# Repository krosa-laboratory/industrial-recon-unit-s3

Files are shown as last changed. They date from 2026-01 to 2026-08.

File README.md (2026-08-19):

# Tactical Cyber-Recon Architecture (Edge-to-C2)

A distributed, Wireless Intrusion Detection System (WIDS) and Signal Intelligence (SIGINT) platform. 

This project separates data acquisition from analysis. It utilizes an ESP32-S3 as a headless, RF edge sensor that streams raw 802.11 and BLE frames via high-speed telemetry to a Python-based Command & Control station for real-time processing, OSINT enrichment, and visualization.

## The Edge Node (Headless ESP32-S3)
A bare-metal, RTOS-driven sensor optimized for maximum radio duty-cycle and zero GUI overhead.

* **MCU:** ESP32-S3-WROOM-1 (Dual-Core Xtensa LX7)
* **Firmware:** PlatformIO / FreeRTOS (C++)
* **Architecture:**
  * **Core 0 (RF Engine):** Dedicated to hardware-level interrupts, 802.11 Promiscuous mode, CSI (Channel State Information) extraction, and passive BLE scanning.
  * **Core 1 (Telemetry Link):** Dedicated to consuming RTOS queues, serializing data into lightweight JSON, and streaming via UART at 921600 baud without blocking the radio.

## The Command & Control Station (Python GUI)
A desktop application for data ingestion, decoding, and tactical analysis.

* **Tech Stack:** Python 3, PyQt6 (UI/UX), PyQtGraph (Real-time data viz), PySerial (Async ingestion).
* **Key Capabilities:**
  * **OSINT Tracker:** Cross-references captured MAC addresses with local OUI databases to identify device manufacturers and track historical Wi-Fi probe requests.
  * **WIDS Dashboard:** Real-time detection of Deauthentication bursts, Rogue APs, and BLE saturation attacks.
  * **CSI Radar:** Generates live waterfall plots from 802.11 subcarrier perturbations to detect physical presence via microwave reflections.
  * **BLE Ecosystem Sniffer:** Parses raw Bluetooth Low Energy payloads to track corporate/IoT devices and exposes unencrypted GATT profiles.

## 🛠️ Development Philosophy & Post-Mortem
*Note: This architecture is a evolution from an initial monolithic design. By pivoting to a headless, distributed model, the system bypasses the processing and memory constraints of local displays (LVGL) and transceivers. This shift dedicates 100% of the ESP32’s compute power and RAM to raw RF acquisition, while offloading heavy OSINT and data visualization workloads to the Command & Control station.*

## ⚠️ Disclaimer
This tool is strictly for educational research, Functional Safety (FuSa) testing, and authorized auditing of Industrial Control Systems (ICS) and corporate networks.

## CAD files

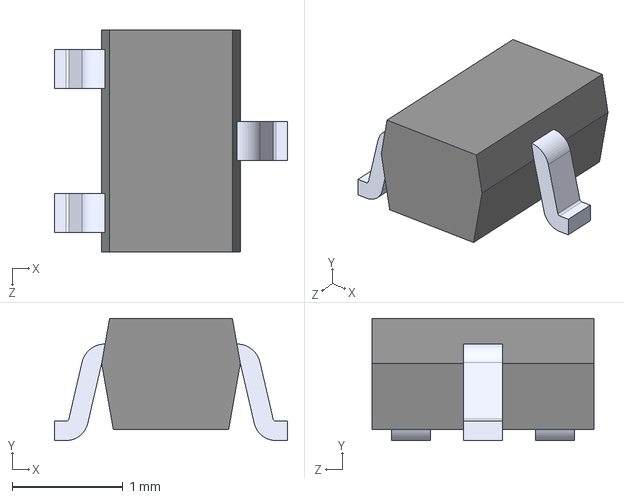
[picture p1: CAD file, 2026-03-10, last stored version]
Hardware/Industrial-Protocol-Auditor-Hardware_V3/Components/PESD2CANFD24V-UX.step
2.10 x 1.10 x 2.00 mm

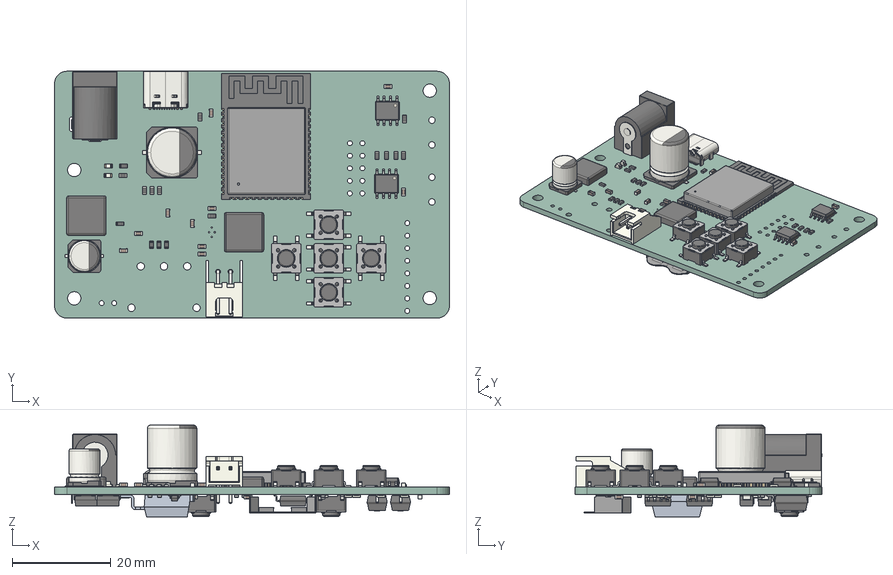
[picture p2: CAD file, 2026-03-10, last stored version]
Hardware/Industrial-Protocol-Auditor-Hardware_V3/Industrial-Protocol-Auditor-Hardware.step
80.0 x 50.1 x 18.6 mm
L_Coilcraft_XAL7020-102 x 2
C_0603_1608Metric x 15
R_0603_1608Metric x 33
SOIC-8_3.9x4.9mm_P1.27mm x 2
ESP32-S3-WROOM-1
SW_SPST_PTS645Sx43SMTR92 x 7
CP_Elec_6.3x7.7
LED_0603_1608Metric x 2
CP_Elec_10x12.5
BarrelJack_Horizontal
USB_C_Receptacle_GCT_USB4105-xx-A_16P_TopMnt_Horizontal
JST_XH_S2B-XH-A_1x02_P2.50mm_Horizontal
SOIC-8_5.3x5.3mm_P1.27mm x 2
SW_DIP_SPSTx01_Slide_6.7x4.1mm_W6.73mm_P2.54mm_LowProfile_JPin x 2
SOT-23
Industrial-Protocol-Auditor-Hardware 1.54.1
D_SMA x 4
BatteryHolder_LINX_BAT-HLD-012-SMT
Fuse_1206_3216Metric
Industrial-Protocol-Auditor-Hardware_PCB

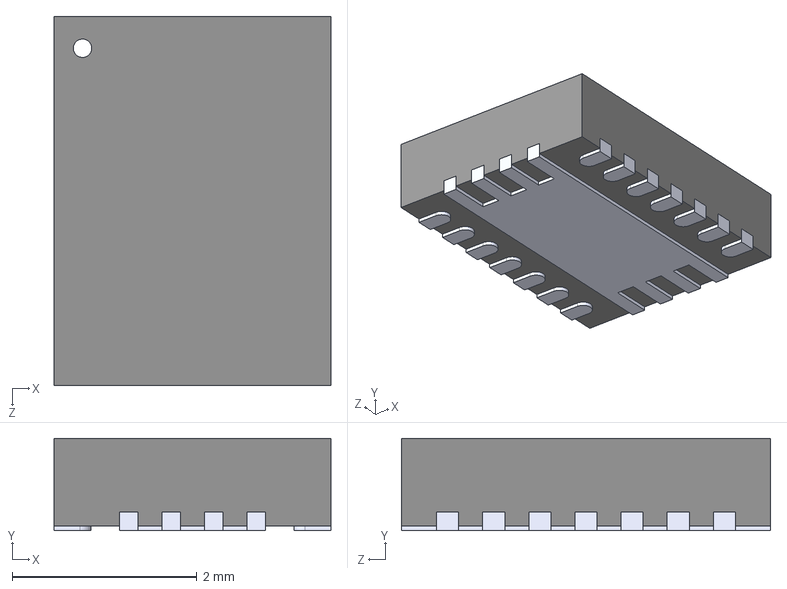
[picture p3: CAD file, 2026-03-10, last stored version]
Hardware/Industrial-Protocol-Auditor-Hardware_V3/Components/TPS63020DSJR.step
3.00 x 1.00 x 4.00 mm

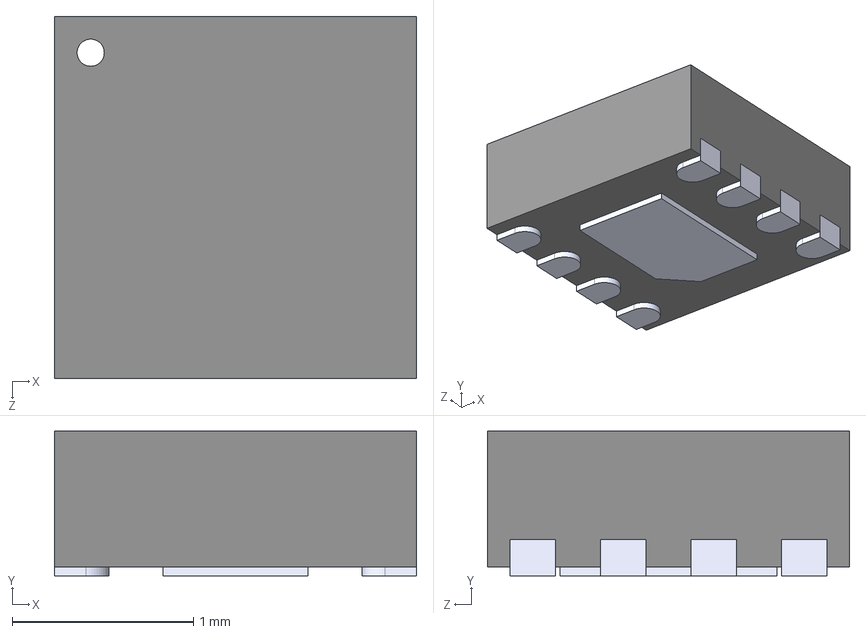
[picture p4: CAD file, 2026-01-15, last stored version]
Hardware/Industrial-Protocol-Auditor-Hardware_V3/Components/MAX17048G_T10.step
2.00 x 0.8 x 2.00 mm

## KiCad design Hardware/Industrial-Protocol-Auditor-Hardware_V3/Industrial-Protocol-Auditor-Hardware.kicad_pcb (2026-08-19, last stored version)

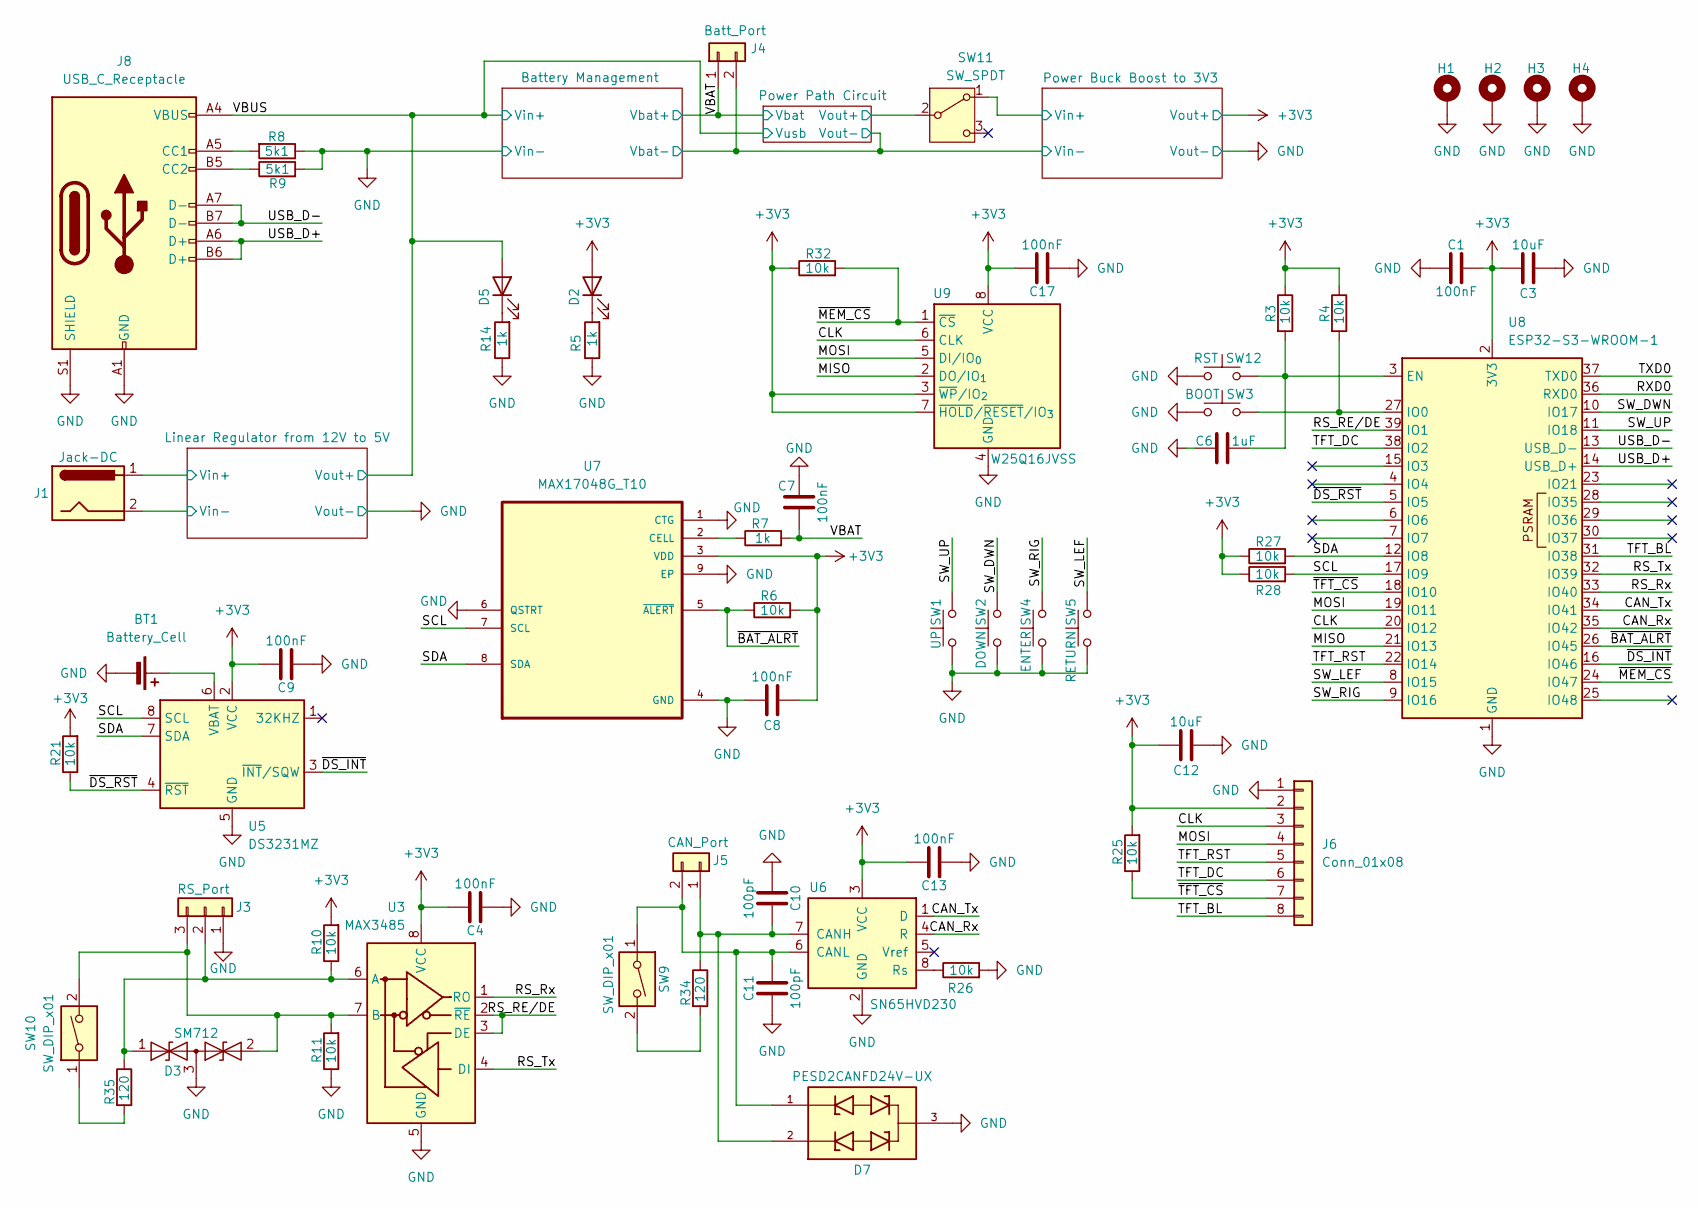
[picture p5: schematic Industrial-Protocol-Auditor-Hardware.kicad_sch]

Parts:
BT1: Battery_Cell; BatteryHolder_LINX_BAT-HLD-012-SMT; LCSC Part C964817
C1, C4, C7, C8, C9, C13, C17: 100nF; C_0603_1608Metric; LCSC Part C14663
C3, C12: 10uF; C_0603_1608Metric; LCSC Part C19702
C6: 1uF; C_0603_1608Metric; LCSC Part C15849
C10, C11: 100pF; C_0603_1608Metric; LCSC Part C14858
D2, D5: LED; LED_0603_1608Metric; LCSC Part C2286
D3: SM712; SOT-23; LCSC Part C7420375
D7: PESD2CANFD24V-UX; SOT-23; PARTREV V.4; LCSC Part C2687131
H1, H2, H3, H4: MountingHole_Pad; MountingHole_2.7mm_M2.5
J1: Jack-DC; BarrelJack_Horizontal; LCSC Part C16214
J3: RS_Port; TerminalBlock_MaiXu_MX126-5.0-03P_1x03_P5.00mm; LCSC Part C474882
J4: Batt_Port; JST_XH_S2B-XH-A_1x02_P2.50mm_Horizontal; LCSC Part C157931
J5: CAN_Port; TerminalBlock_MaiXu_MX126-5.0-02P_1x02_P5.00mm; LCSC Part C474881
J6: Conn_01x08; PinHeader_1x08_P2.54mm_Vertical; LCSC Part C157914
J8: USB_C_Receptacle; USB_C_Receptacle_GCT_USB4105-xx-A_16P_TopMnt_Horizontal; LCSC Part C393939
R3, R4, R6, R10, R11, R21, R25, R26, R27, R28, R32: 10k; R_0603_1608Metric; LCSC Part C25804
R5, R7, R14: 1k; R_0603_1608Metric; LCSC Part C21190
R8, R9: 5k1; R_0603_1608Metric; LCSC Part C23186
R34, R35: 120; R_0603_1608Metric; LCSC Part C22787
SW1: UP; SW_SPST_PTS645Sx43SMTR92; LCSC Part C19191552
SW2: DOWN; SW_SPST_PTS645Sx43SMTR92; LCSC Part C19191552
SW3: BOOT; SW_SPST_PTS645Sx43SMTR92; LCSC Part C19191552
SW4: ENTER; SW_SPST_PTS645Sx43SMTR92; LCSC Part C19191552
SW5: RETURN; SW_SPST_PTS645Sx43SMTR92; LCSC Part C19191552
SW9, SW10: SW_DIP_x01; SW_DIP_SPSTx01_Slide_6.7x4.1mm_W6.73mm_P2.54mm_LowProfile_J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
SW11: SW_SPDT; SS-12D11
SW12: RST; SW_SPST_PTS645Sx43SMTR92; LCSC Part C19191552
U3: MAX3485; SOIC-8_3.9x4.9mm_P1.27mm; LCSC Part C9943
U5: DS3231MZ; SOIC-8_5.3x5.3mm_P1.27mm; LCSC Part C107410
U6: SN65HVD230; SOIC-8_3.9x4.9mm_P1.27mm; LCSC Part C12084
U7: MAX17048G_T10; DFN-8-1EP_2x2mm_P0.5mm_EP0.8x1.6mm; LCSC Part C2682616
U8: ESP32-S3-WROOM-1; LCSC Part C2913202
U9: W25Q16JVSS; SOIC-8_5.3x5.3mm_P1.27mm; LCSC Part C82317

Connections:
+3V3: C1.2, C3.2, C4.2, C8.1, C9.2, C12.2, C13.2, C17.2, D2.2 (A), J6.2, R3.1, R4.1, R6.2, R10.2, R21.2, R25.2, R27.1, R28.1, R32.1, U3.8 (VCC), U5.2 (VCC), U6.3 (VCC), U7.3 (VDD), U8.2 (3V3), U9.3 (~WP/IO_{2}), U9.7 (~HOLD/~RESET/IO_{3}), U9.8 (VCC); also elsewhere on the board
/CAN_Rx: U6.4 (R), U8.35 (IO42)
/CAN_Tx: U6.1 (D), U8.34 (IO41)
/CLK: J6.3, U8.20 (IO12), U9.6 (CLK)
/Linear Regulator from 12V to 5V/Vin+: J1.1; also elsewhere on the board
/MISO: U8.21 (IO13), U9.2 (DO/IO_{1})
/MOSI: J6.4, U8.19 (IO11), U9.5 (DI/IO_{0})
/Power Buck Boost to 3V3/Vin+: SW11.1 (A); also elsewhere on the board
/Power Path Circuit/Vout+: SW11.2 (B); also elsewhere on the board
/RS_RE/DE: U3.2 (~RE), U3.3 (DE), U8.39 (IO1)
/RS_Rx: U3.1 (RO), U8.33 (IO40)
/RS_Tx: U3.4 (DI), U8.32 (IO39)
/RXD0: U8.36 (RXD0)
/SCL: R28.2, U5.8 (SCL), U7.7 (SCL), U8.17 (IO9)
/SDA: R27.2, U5.7 (SDA), U7.8 (SDA), U8.12 (IO8)
/SW_DWN: SW2.2, U8.10 (IO17)
/SW_LEF: SW5.2, U8.8 (IO15)
/SW_RIG: SW4.2, U8.9 (IO16)
/SW_UP: SW1.2, U8.11 (IO18)
/TFT_BL: J6.8, U8.31 (IO38)
/TFT_DC: J6.6, U8.38 (IO2)
/TFT_RST: J6.5, U8.22 (IO14)
/TXD0: U8.37 (TXD0)
/USB_D+: J8.A6 (D+), J8.B6 (D+), U8.14 (USB_D+)
/USB_D-: J8.A7 (D-), J8.B7 (D-), U8.13 (USB_D-)
/VBAT: C7.1, J4.1, R7.2; also elsewhere on the board
/VBUS: D5.2 (A), J8.A4 (VBUS), J8.A9 (VBUS), J8.B4 (VBUS), J8.B9 (VBUS); also elsewhere on the board
/~BAT_ALRT: R6.1, U7.5 (~ALERT), U8.26 (IO45)
/~DS_INT: U5.3 (~INT/SQW), U8.16 (IO46)
/~DS_RST: R21.1, U5.4 (~RST), U8.5 (IO5)
/~MEM_CS: R32.2, U8.24 (IO47), U9.1 (~CS)
/~TFT_CS: J6.7, R25.1, U8.18 (IO10)
GND: BT1.2 (-), C1.1, C3.1, C4.1, C6.1, C7.2, C8.2, C9.1, C10.1, C11.1, C12.1, C13.1, C17.1, D3.3 (common), D7.3, H1.1, H2.1, H3.1, H4.1, J1.2, J3.1, J4.2, J6.1, J8.A1 (GND), J8.A12 (GND), J8.B1 (GND), J8.B12 (GND), J8.S1 (SHIELD), R5.1, R8.1, R9.2, R11.1, R14.1, R26.2, SW1.1, SW2.1, SW3.1, SW4.1, SW5.1, SW12.1, U3.5 (GND), U5.5 (GND), U6.2 (GND), U7.1 (CTG), U7.4 (GND), U7.6 (QSTRT), U7.9 (EP), U8.1 (GND), U8.40 (GND), U8.41 (GND), U9.4 (GND); also elsewhere on the board
unnamed: BT1.1 (+), U5.6 (VBAT)
unnamed: D2.1 (K), R5.2
unnamed: D3.1 (A1), J3.2, R10.1, R35.1, U3.6 (A)
unnamed: D3.2 (A2), J3.3, R11.2, SW10.2, U3.7 (B)
unnamed: D5.1 (K), R14.2
unnamed: C10.2, D7.2, J5.1, R34.1, U6.7 (CANH)
unnamed: C11.2, D7.1, J5.2, SW9.1, U6.6 (CANL)
unnamed: J8.A5 (CC1), R8.2
unnamed: J8.B5 (CC2), R9.1
unnamed: R34.2, SW9.2
unnamed: R35.2, SW10.1
unnamed: R26.1, U6.8 (Rs)
unnamed: R7.1, U7.2 (CELL)
unnamed: C6.2, R3.2, SW12.2, U8.3 (EN)
unnamed: R4.2, SW3.2, U8.27 (IO0)

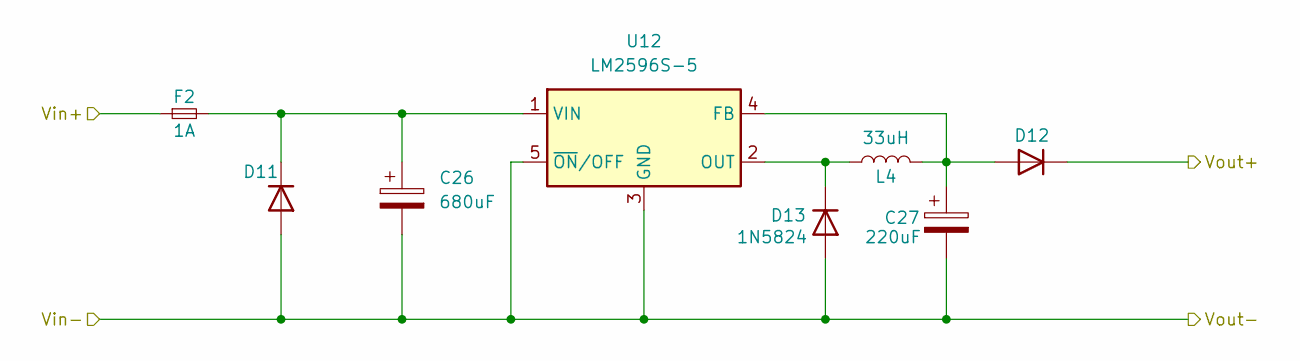
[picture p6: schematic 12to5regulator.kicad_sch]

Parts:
C26: 680uF; CP_Elec_10x12.5; LCSC Part C2983320
C27: 220uF; CP_Elec_6.3x7.7; LCSC Part C2887273
D11, D12, D13: 1N5824; D_SMA; LCSC Part C8678
F2: 1A; Fuse_1206_3216Metric; LCSC Part C720075
L4: 33uH; L_Sunlord_MWSA1005S; LCSC Part C6364680
U12: LM2596S-5; TO-263-5_TabPin3; LCSC Part C347421

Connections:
/Linear Regulator from 12V to 5V/Vin+: F2.1; also elsewhere on the board
/VBUS: D12.1 (K); also elsewhere on the board
GND: C26.2, C27.2, D11.2 (A), D13.2 (A), U12.3 (GND), U12.5 (~ON/OFF); also elsewhere on the board
unnamed: C26.1, D11.1 (K), F2.2, U12.1 (VIN)
unnamed: C27.1, D12.2 (A), L4.2, U12.4 (FB)
unnamed: D13.1 (K), L4.1, U12.2 (OUT)

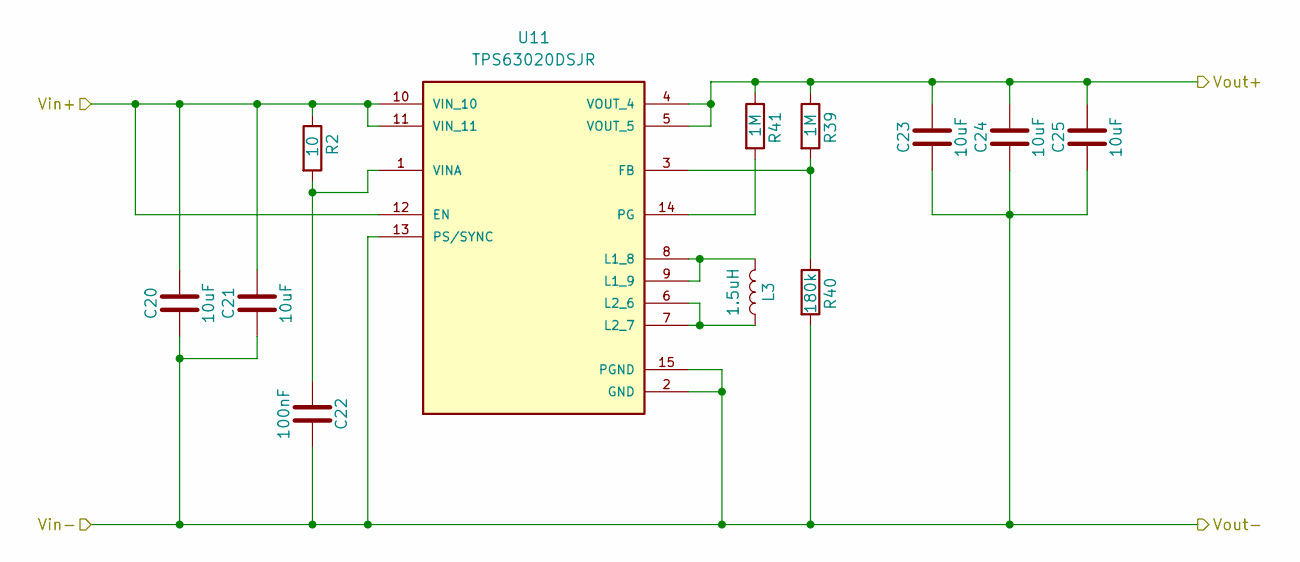
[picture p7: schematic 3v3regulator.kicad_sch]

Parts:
C20, C21, C23, C24, C25: 10uF; C_0603_1608Metric; LCSC Part C19702
C22: 100nF; C_0603_1608Metric; LCSC Part C14663
L3: 1.5uH; L_Chilisin_BMRx00060630; LCSC Part C5189745
R2: 10; R_0603_1608Metric; LCSC Part C22859
R39, R41: 1M; R_0603_1608Metric; LCSC Part C22935
R40: 180k; R_0603_1608Metric; LCSC Part C2906999
U11: TPS63020DSJR; IC_TPS63020DSJR; LCSC Part C15483

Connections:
+3V3: C23.2, C24.2, C25.2, R39.1, R41.1, U11.4 (VOUT_4), U11.5 (VOUT_5); also elsewhere on the board
/Power Buck Boost to 3V3/Vin+: C20.2, C21.2, R2.1, U11.10 (VIN_10), U11.11 (VIN_11), U11.12 (EN); also elsewhere on the board
GND: C20.1, C21.1, C22.2, C23.1, C24.1, C25.1, R40.2, U11.2 (GND), U11.13 (PS/SYNC), U11.15 (PGND); also elsewhere on the board
unnamed: R39.2, R40.1, U11.3 (FB)
unnamed: L3.2, U11.8 (L1_8), U11.9 (L1_9)
unnamed: L3.1, U11.6 (L2_6), U11.7 (L2_7)
unnamed: R41.2, U11.14 (PG)
unnamed: C22.1, R2.2, U11.1 (VINA)

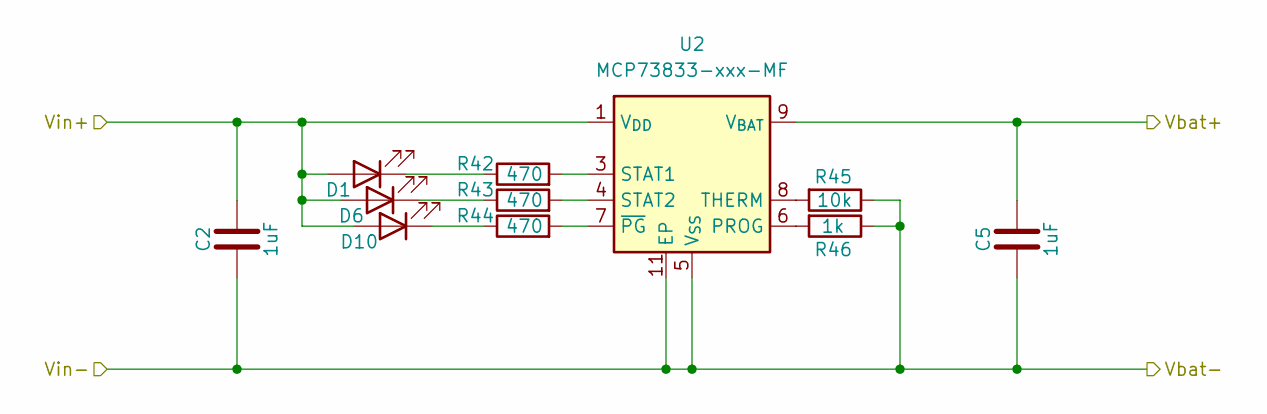
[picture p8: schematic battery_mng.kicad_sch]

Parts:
C2, C5: 1uF; C_0603_1608Metric; LCSC Part C15849
D1, D6, D10: LED; LED_0603_1608Metric; LCSC Part C2286
R42, R43, R44: 470; R_0603_1608Metric; LCSC Part C23179
R45: 10k; R_0603_1608Metric; LCSC Part C25804
R46: 1k; R_0603_1608Metric; LCSC Part C21190
U2: MCP73833-xxx-MF; DFN-10-1EP_3x3mm_P0.5mm_EP1.58x2.35mm; LCSC Part C340160

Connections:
/VBAT: C5.2, U2.9 (V_{BAT}), U2.10 (V_{BAT}); also elsewhere on the board
/VBUS: C2.2, D1.2 (A), D6.2 (A), D10.2 (A), U2.1 (V_{DD}), U2.2 (V_{DD}); also elsewhere on the board
GND: C2.1, C5.1, R45.1, R46.1, U2.5 (V_{SS}), U2.11 (EP); also elsewhere on the board
unnamed: D1.1 (K), R42.1
unnamed: D6.1 (K), R43.1
unnamed: D10.1 (K), R44.1
unnamed: R46.2, U2.6 (PROG)
unnamed: R42.2, U2.3 (STAT1)
unnamed: R43.2, U2.4 (STAT2)
unnamed: R45.2, U2.8 (THERM)
unnamed: R44.2, U2.7 (~PG)

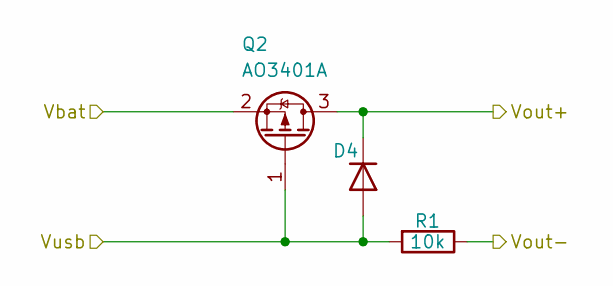
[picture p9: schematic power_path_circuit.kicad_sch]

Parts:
D4: 1N5824; D_SMA; LCSC Part C8678
Q2: AO3401A; SOT-23; LCSC Part C15127
R1: 10k; R_0603_1608Metric; LCSC Part C25804

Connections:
/Power Path Circuit/Vout+: D4.1 (K), Q2.3 (D); also elsewhere on the board
/VBAT: Q2.2 (S); also elsewhere on the board
/VBUS: D4.2 (A), Q2.1 (G), R1.2; also elsewhere on the board
GND: R1.1; also elsewhere on the board

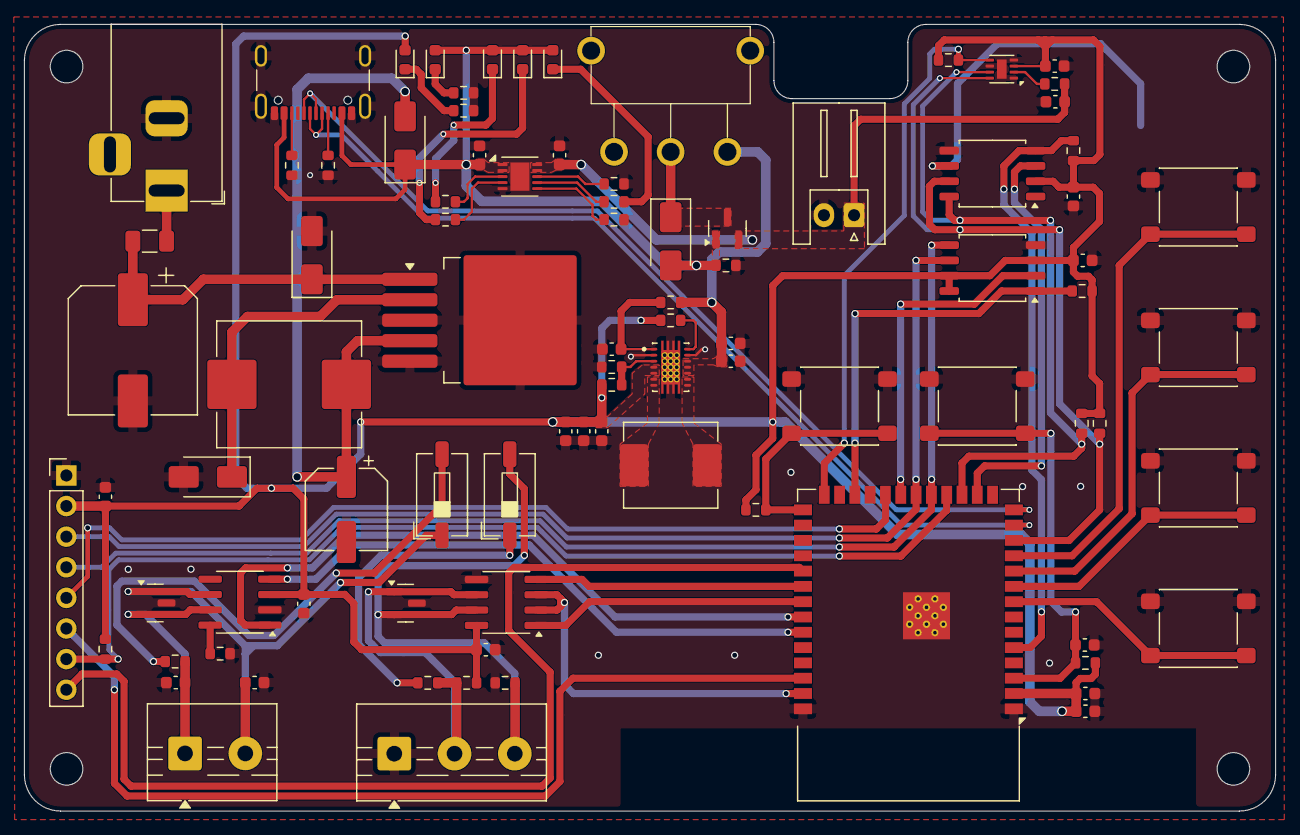
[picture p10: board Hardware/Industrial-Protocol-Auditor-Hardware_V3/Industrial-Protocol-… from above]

Board: 2 copper layers, 103.8 x 65.3 mm, 94 parts (1 on the bottom side), 62 nets.

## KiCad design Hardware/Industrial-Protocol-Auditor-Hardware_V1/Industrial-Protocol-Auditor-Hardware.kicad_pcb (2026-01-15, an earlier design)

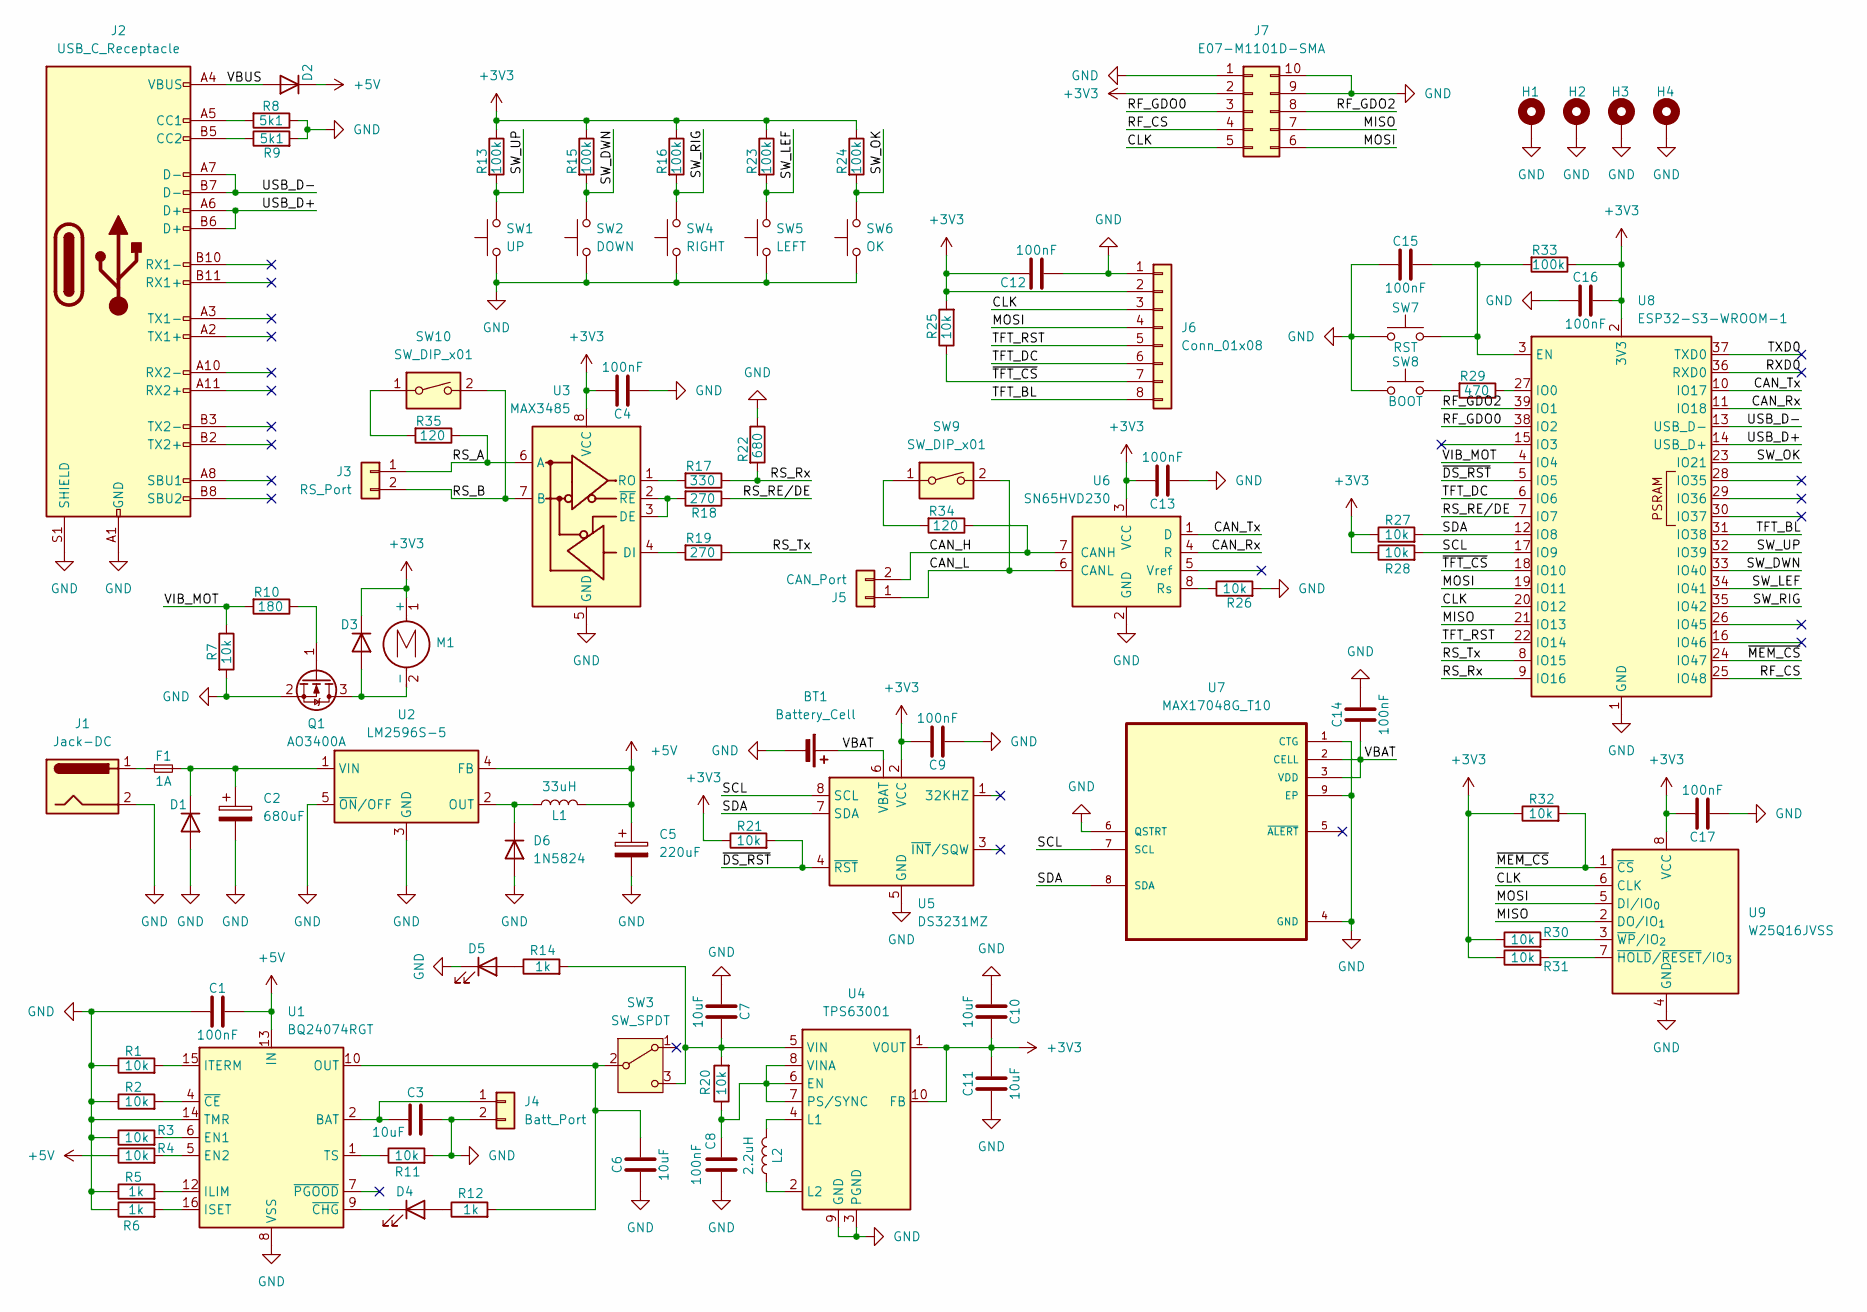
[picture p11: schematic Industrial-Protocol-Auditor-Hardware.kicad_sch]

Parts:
BT1: Battery_Cell; BatteryHolder_LINX_BAT-HLD-012-SMT; LCSC Part C964817
C1, C4, C8, C9, C12, C13, C14, C15, C16, C17: 100nF; C_0603_1608Metric; LCSC Part C14663
C2: 680uF; CP_Elec_10x12.5; LCSC Part C2983320
C3, C6, C7, C10, C11: 10uF; C_0603_1608Metric; LCSC Part C19702
C5: 220uF; CP_Elec_6.3x7.7; LCSC Part C2887273
D1, D2, D3, D6: 1N5824; D_SMA; LCSC Part C8678
D4, D5: LED; LED_0603_1608Metric; LCSC Part C2286
F1: 1A; Fuse_1206_3216Metric; LCSC Part C720075
H1, H2, H3, H4: MountingHole_Pad; MountingHole_2.7mm_M2.5
J1: Jack-DC; BarrelJack_Horizontal; LCSC Part C16214
J2: USB_C_Receptacle; USB_C_Receptacle_GCT_USB4105-xx-A_16P_TopMnt_Horizontal; LCSC Part C393939
J3: RS_Port; TerminalBlock_MaiXu_MX126-5.0-02P_1x02_P5.00mm; LCSC Part C474881
J4: Batt_Port; JST_XH_S2B-XH-A_1x02_P2.50mm_Horizontal; LCSC Part C157931
J5: CAN_Port; TerminalBlock_MaiXu_MX126-5.0-02P_1x02_P5.00mm; LCSC Part C474881
J6: Conn_01x08; JST_XH_S8B-XH-A_1x08_P2.50mm_Horizontal; LCSC Part C157914
J7: E07-M1101D-SMA; PinHeader_2x05_P2.54mm_Vertical
L1: 33uH; L_Coilcraft_XAL7020-102; LCSC Part C6364680
L2: 2.2uH; L_Coilcraft_XAL7020-102; LCSC Part C86092
M1: Motor_DC; PinHeader_1x02_P2.54mm_Vertical
Q1: AO3400A; SOT-23; LCSC Part C20917
R1, R2, R3, R4, R7, R11, R20, R21, R25, R26, R27, R28, R30, R31, R32: 10k; R_0603_1608Metric; LCSC Part C25804
R5, R6, R12, R14: 1k; R_0603_1608Metric; LCSC Part C21190
R8, R9: 5k1; R_0603_1608Metric; LCSC Part C23186
R10: 180; R_0603_1608Metric; LCSC Part C2907000
R13, R15, R16, R23, R24, R33: 100k; R_0603_1608Metric; LCSC Part C25803
R17: 330; R_0603_1608Metric; LCSC Part C23138
R18, R19: 270; R_0603_1608Metric; LCSC Part C22966
R22: 680; R_0603_1608Metric; LCSC Part C23228
R29: 470; R_0603_1608Metric; LCSC Part C23179
R34, R35: 120; R_0603_1608Metric; LCSC Part C23228
SW1: UP; SW_SPST_PTS645Sx43SMTR92; LCSC Part C19191552
SW2: DOWN; SW_SPST_PTS645Sx43SMTR92; LCSC Part C19191552
SW3: SW_SPDT; SS-12D11; LCSC Part C431548
SW4: RIGHT; SW_SPST_PTS645Sx43SMTR92; LCSC Part C19191552
SW5: LEFT; SW_SPST_PTS645Sx43SMTR92; LCSC Part C19191552
SW6: OK; SW_SPST_PTS645Sx43SMTR92; LCSC Part C19191552
SW7: RST; SW_SPST_PTS645Sx43SMTR92; LCSC Part C19191552
SW8: BOOT; SW_SPST_PTS645Sx43SMTR92; LCSC Part C19191552
SW9, SW10: SW_DIP_x01; SW_DIP_SPSTx01_Slide_6.7x4.1mm_W6.73mm_P2.54mm_LowProfile_J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
U1: BQ24074RGT; VQFN-16-1EP_3x3mm_P0.5mm_EP1.6x1.6mm; LCSC Part C2861252
U2: LM2596S-5; TO-263-5_TabPin3; LCSC Part C347421
U3: MAX3485; SOIC-8_3.9x4.9mm_P1.27mm; LCSC Part C9943
U4: TPS63001; Texas_DRC0010J_ThermalVias; LCSC Part C28060
U5: DS3231MZ; SOIC-8_5.3x5.3mm_P1.27mm; LCSC Part C107410
U6: SN65HVD230; SOIC-8_3.9x4.9mm_P1.27mm; LCSC Part C12084
U7: MAX17048G_T10; DFN-8-1EP_2x2mm_P0.5mm_EP0.8x1.6mm; LCSC Part C2682616
U8: ESP32-S3-WROOM-1; LCSC Part C2913202
U9: W25Q16JVSS; SOIC-8_5.3x5.3mm_P1.27mm; LCSC Part C82317

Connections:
+3V3: C4.2, C9.2, C10.2, C11.2, C12.2, C13.2, C16.2, C17.2, D3.1 (K), J6.2, J7.2, M1.1 (+), R13.1, R15.1, R16.1, R21.1, R23.1, R24.1, R25.2, R27.1, R28.1, R30.1, R31.1, R32.1, R33.1, U3.8 (VCC), U4.1 (VOUT), U4.10 (FB), U5.2 (VCC), U6.3 (VCC), U8.2 (3V3), U9.8 (VCC)
+5V: C1.2, C5.1, D2.1 (K), L1.2, R4.1, U1.13 (IN), U2.4 (FB)
/CAN_H: J5.2, R34.1, U6.7 (CANH)
/CAN_L: J5.1, SW9.2, U6.6 (CANL)
/CAN_Rx: U6.4 (R), U8.11 (IO18)
/CAN_Tx: U6.1 (D), U8.10 (IO17)
/CLK: J6.3, J7.5, U8.20 (IO12), U9.6 (CLK)
/MISO: J7.7, U8.21 (IO13), U9.2 (DO/IO_{1})
/MOSI: J6.4, J7.6, U8.19 (IO11), U9.5 (DI/IO_{0})
/RF_CS: J7.4, U8.25 (IO48)
/RF_GDO0: J7.3, U8.38 (IO2)
/RF_GDO2: J7.8, U8.39 (IO1)
/RS_A: J3.1, R35.1, U3.6 (A)
/RS_B: J3.2, SW10.2, U3.7 (B)
/RS_RE/DE: R18.1, U8.7 (IO7)
/RS_Rx: R17.1, R22.2, U8.9 (IO16)
/RS_Tx: R19.1, U8.8 (IO15)
/RXD0: U8.36 (RXD0)
/SCL: R28.2, U5.8 (SCL), U7.7 (SCL), U8.17 (IO9)
/SDA: R27.2, U5.7 (SDA), U7.8 (SDA), U8.12 (IO8)
/SW_DWN: R15.2, SW2.2, U8.33 (IO40)
/SW_LEF: R23.2, SW5.2, U8.34 (IO41)
/SW_OK: R24.2, SW6.2, U8.23 (IO21)
/SW_RIG: R16.2, SW4.2, U8.35 (IO42)
/SW_UP: R13.2, SW1.2, U8.32 (IO39)
/TFT_BL: J6.8, U8.31 (IO38)
/TFT_DC: J6.6, U8.6 (IO6)
/TFT_RST: J6.5, U8.22 (IO14)
/TXD0: U8.37 (TXD0)
/USB_D+: J2.A6 (D+), J2.B6 (D+), U8.14 (USB_D+)
/USB_D-: J2.A7 (D-), J2.B7 (D-), U8.13 (USB_D-)
/VBAT: BT1.1 (+), C14.1, U5.6 (VBAT), U7.2 (CELL), U7.3 (VDD)
/VBUS: D2.2 (A), J2.A4 (VBUS), J2.A9 (VBUS), J2.B4 (VBUS), J2.B9 (VBUS)
/VIB_MOT: R7.1, R10.2, U8.4 (IO4)
/~DS_RST: R21.2, U5.4 (~RST), U8.5 (IO5)
/~MEM_CS: R32.2, U8.24 (IO47), U9.1 (~CS)
/~TFT_CS: J6.7, R25.1, U8.18 (IO10)
GND: BT1.2 (-), C1.1, C2.2, C3.2, C4.1, C5.2, C6.1, C7.1, C8.1, C9.1, C10.1, C11.1, C12.1, C13.1, C14.2, C15.1, C16.1, C17.1, D1.2 (A), D5.1 (K), D6.2 (A), H1.1, H2.1, H3.1, H4.1, J1.2, J2.A1 (GND), J2.A12 (GND), J2.B1 (GND), J2.B12 (GND), J2.S1 (SHIELD), J4.2, J6.1, J7.1, J7.9, J7.10, Q1.2 (S), R1.1, R2.1, R3.1, R5.1, R6.1, R7.2, R8.1, R9.2, R11.2, R22.1, R26.2, SW1.1, SW2.1, SW4.1, SW5.1, SW6.1, SW7.1, SW8.1, U1.8 (VSS), U1.14 (TMR), U1.17 (VSS), U2.3 (GND), U2.5 (~ON/OFF), U3.5 (GND), U4.3 (PGND), U4.9 (GND), U4.11 (PGND), U5.5 (GND), U6.2 (GND), U7.1 (CTG), U7.4 (GND), U7.6 (QSTRT), U7.9 (EP), U8.1 (GND), U8.40 (GND), U8.41 (GND), U9.4 (GND)
unnamed: C2.1, D1.1 (K), F1.2, U2.1 (VIN)
unnamed: D3.2 (A), M1.2 (-), Q1.3 (D)
unnamed: D4.2 (A), R12.1
unnamed: D4.1 (K), U1.9 (~CHG)
unnamed: D5.2 (A), R14.1
unnamed: D6.1 (K), L1.1, U2.2 (OUT)
unnamed: F1.1, J1.1
unnamed: J2.A5 (CC1), R8.2
unnamed: J2.B5 (CC2), R9.1
unnamed: C3.1, J4.1, U1.2 (BAT), U1.3 (BAT)
unnamed: Q1.1 (G), R10.1
unnamed: R29.2, SW8.2
unnamed: R34.2, SW9.1
unnamed: R35.2, SW10.1
unnamed: C6.2, R12.2, SW3.2 (B), U1.10 (OUT), U1.11 (OUT)
unnamed: C7.2, R14.2, R20.2, SW3.3 (C), U4.5 (VIN)
unnamed: R3.2, U1.6 (EN1)
unnamed: R4.2, U1.5 (EN2)
unnamed: R5.2, U1.12 (ILIM)
unnamed: R6.2, U1.16 (ISET)
unnamed: R1.2, U1.15 (ITERM)
unnamed: R11.1, U1.1 (TS)
unnamed: R2.2, U1.4 (~CE)
unnamed: R18.2, U3.2 (~RE), U3.3 (DE)
unnamed: R19.2, U3.4 (DI)
unnamed: R17.2, U3.1 (RO)
unnamed: C8.2, R20.1, U4.6 (EN), U4.7 (PS/SYNC), U4.8 (VINA)
unnamed: L2.2, U4.4 (L1)
unnamed: L2.1, U4.2 (L2)
unnamed: R26.1, U6.8 (Rs)
unnamed: C15.2, R33.2, SW7.2, U8.3 (EN)
unnamed: R29.1, U8.27 (IO0)
unnamed: R31.2, U9.7 (~HOLD/~RESET/IO_{3})
unnamed: R30.2, U9.3 (~WP/IO_{2})

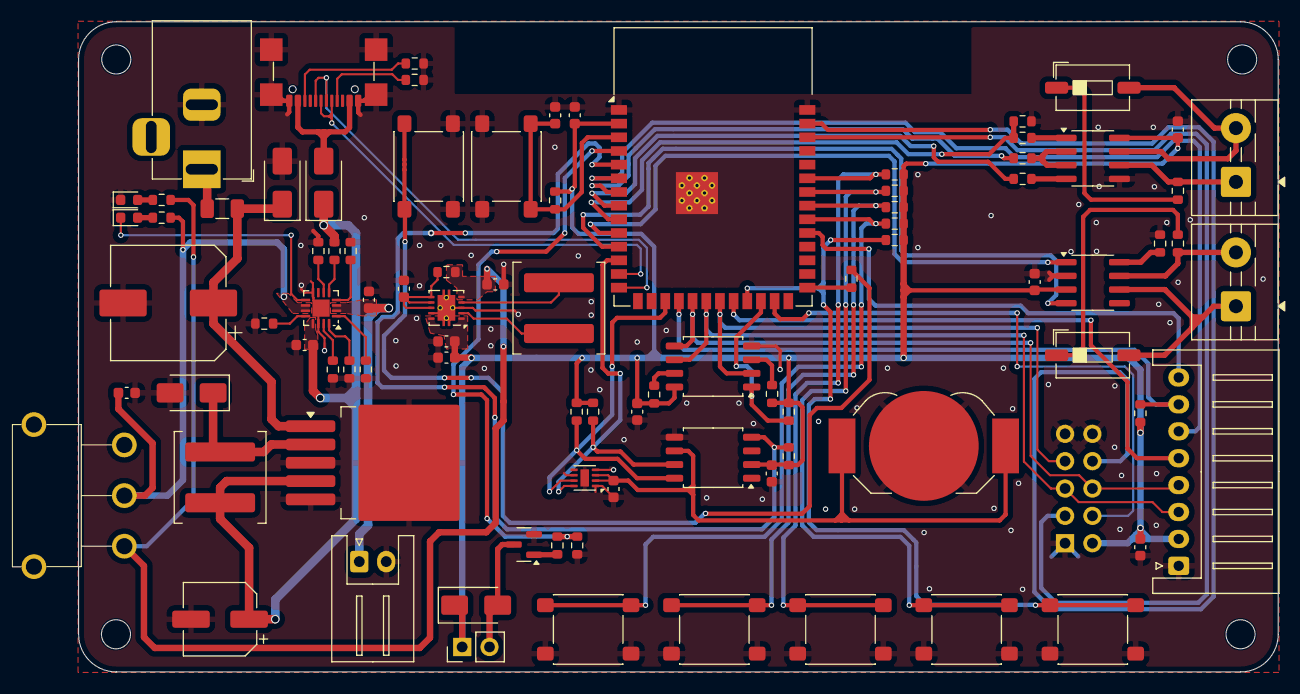
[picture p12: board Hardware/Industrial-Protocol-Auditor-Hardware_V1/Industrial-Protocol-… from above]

Board: 2 copper layers, 111.5 x 60.4 mm, 94 parts (1 on the bottom side), 70 nets.

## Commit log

2026-01-15 Added files of hardware designs, assignments and power consumptions used for the project.
    [Industrial-Protocol-Auditor-Hardware.csv, Industrial-Protocol-Auditor-Hardware.kicad_pcb, Industrial-Protocol-Auditor-Hardware.kicad_sch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]
2026-01-29 Created the ESP-IDF project wioth Vs Code extension to try ESP32-S3 microcontroller in the custom PCB for the device.
    [Industrial-Protocol-Auditor-Hardware.kicad_sch, partitions.csv]
2026-01-29 Tested display functioning with custom PCB and ESP-IDF extension. All works fine by now.
2026-02-06 Removed ESP-IDF files. I'm migrating to PlatformIO + VS Code.
    [partitions.csv]
2026-02-10 Prepared a test for an ESP32-WROOM-32 NodeMCU to test. Maybe I develop the prototype in breadboard and let the PCB unused because it has problems with USB comms.
2026-02-17 Fixed a bug that occurs entering the CAN Bus screen and cause the screen to not start automatically, needing a button activation to strat emulating readings.
2026-02-22 Structured again the folder structure and fixed all #include and classes to work fine the Main menu and the CAN Bus tools.
2026-02-22 Fixed Can bus tools internal private variables name and implemented the WiFi Scanner tool.
2026-03-02 Added a WIDS (Wireless Intruder Detection System) tool in the WiFi menu.
2026-03-10 Created a new version of the Hardware, fixing some problems finded in the first attempt of PCB.
    [12to5regulator.kicad_sch, 3v3regulator.kicad_sch, Industrial-Protocol-Auditor-Hardware.csv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]
2026-08-19 Hardware V3
    Made fixes and minor changes into the V3 PCB.
    [12to5regulator.kicad_sch, 3v3regulator.kicad_sch, Industrial-Protocol-Auditor-Hardware.csv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]
2026-08-19 Refactor to PC tool
    Removed all Hardware docs and the existing firmware made for a physical hand tool to refactor the project to a PC tool.
    [12to5regulator.kicad_sch, 3v3regulator.kicad_sch, Industrial-Protocol-Auditor-Hardware.csv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]
